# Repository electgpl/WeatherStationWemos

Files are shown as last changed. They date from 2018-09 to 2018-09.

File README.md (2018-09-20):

# Estación Meteorológica WiFi v1.0 

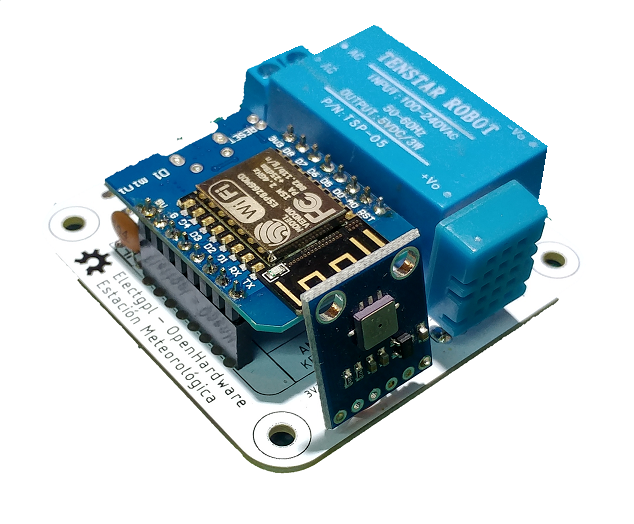
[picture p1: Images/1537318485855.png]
N|Solid


Esta es una estación Meteorológica Inalámbrica mediante WiFi, basada en el SoC ESP8266 para la comunicación y los sensores: BMP085/180, DHT11 y LDR.
Para una mejor precisión de medición, la temperatura se extrae del sensor Bosch en lugar del sensor DHT11, quedando así el DHT11 solo para indicar la humedad relativa.
El firmware cuenta con la biblioteca WiFiManager para aumentar la facilidad de autenticación para el usuario y los datos son enviados directamente a ThingSpeak.
Estos datos son enviados cada 5 minutos para mantener las buenas costumbres de frecuencia de datos en el servidor ThingSpeak, en el caso de parámetros meteorológicos no es necesaria la actualización constante de los datos, estos cambian de forma lenta.

## Controles - v1.0

  - Core - **ESP8266 - WEMOS D1 Mini**
  - Sensor de Presión y Temperatura - **BMP085 - BMP180**
  - Sensor de Humedad y Temperatura - **DHT11**
  - Sensor de Luminosidad - **LDR**
  - Botón de configuración para restablecer datos de fabrica
  - Servidor - **ThingSpeak**
  - Control WiFi - **WiFiManager**

## Alimentación

> Diseñado para ser alimentado con fuente de alimentación de 100 a 240Vac 3W

### Diseño

> Diseñado con EAGLE, en solo dos capas con componentes THT para facilitar
> la integración al alumno, el desarrollo del PCB en el hogar y mantener
> el menor costo posible.

### Medición OnLine en Tiempo Real ThingSpeak Channel 128756
https://thingspeak.com/channels/128756

Patrocinado
----
¿Dónde fabricamos nuestros PCBs?
Nuestros PCBs los fabricamos con la empresa PCBWay, esta empresa nos permite realizar pequeñas cantidades como prototipos rápidos para nuestros desarrollos a medida.
También nos permite realizar grandes producciones para realizar proyectos comerciales.
Servicio de prototipo de PCB por tan solo $5 las 10 unidades.
Cada nuevo miembro recibirá un bono de $5, más servicio express de 24Hs o 48Hs.
Servicio de ensamblado de PCB por $88 más envió gratis en todo el mundo, más esténcil, más componentes.
Un servicio de calidad!
https://www.pcbway.es/

N|Solid (https://www.pcbway.es/)

License
----

MIT

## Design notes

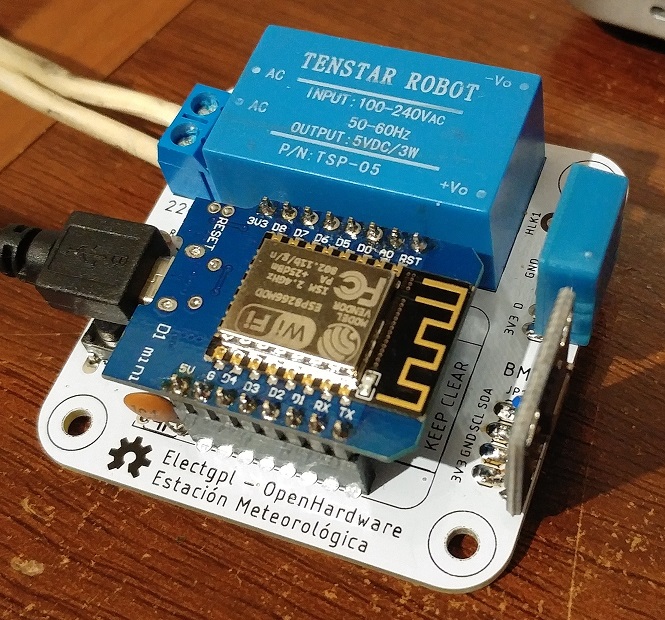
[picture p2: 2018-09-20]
Images/20180918_194005_HDR.jpg

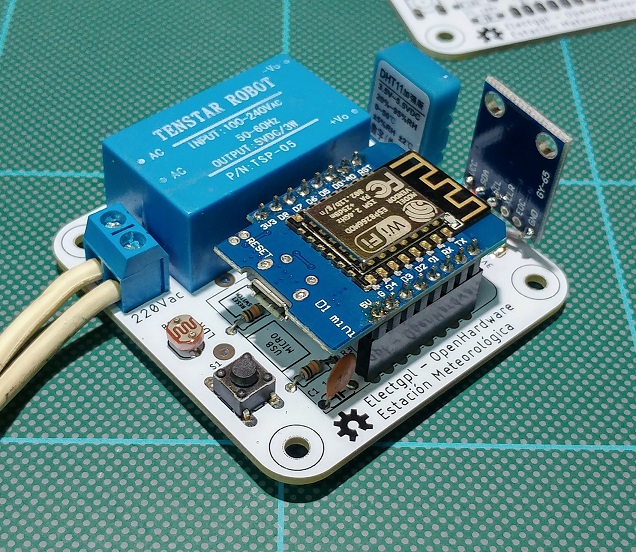
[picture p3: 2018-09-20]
Images/20180918_203112_HDR.jpg

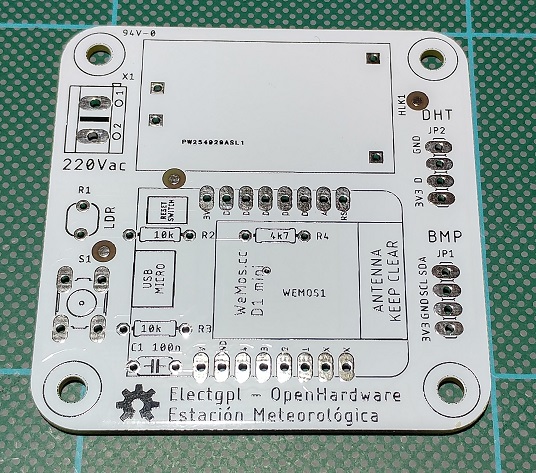
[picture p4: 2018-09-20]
Images/20180918_203201_HDR.jpg

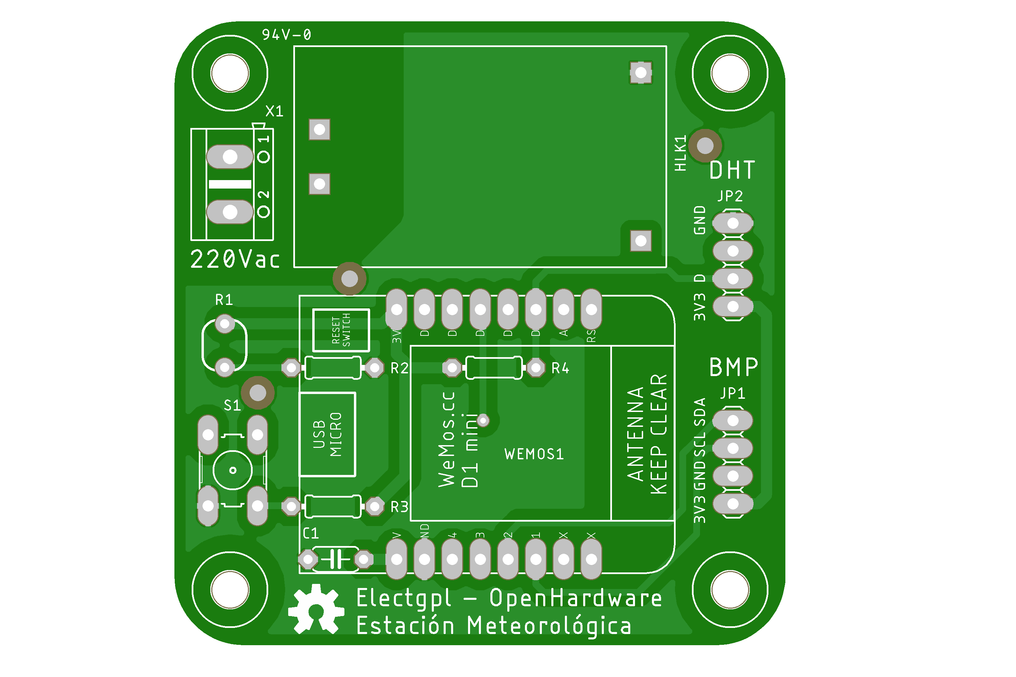
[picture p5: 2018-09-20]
Preview/EstacionESP8266_v1_T.png

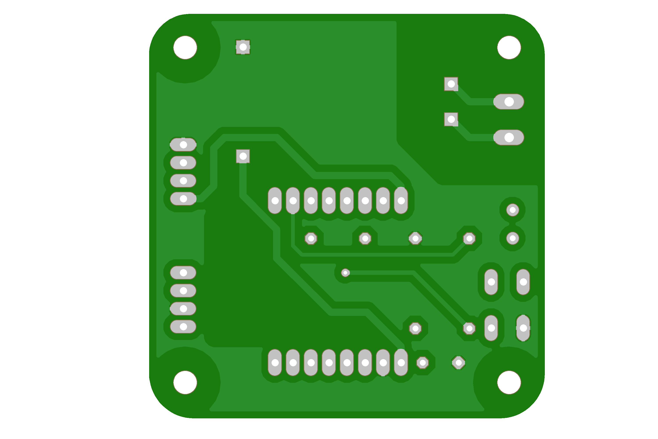
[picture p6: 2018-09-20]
Preview/EstacionESP8266_v1_B.png

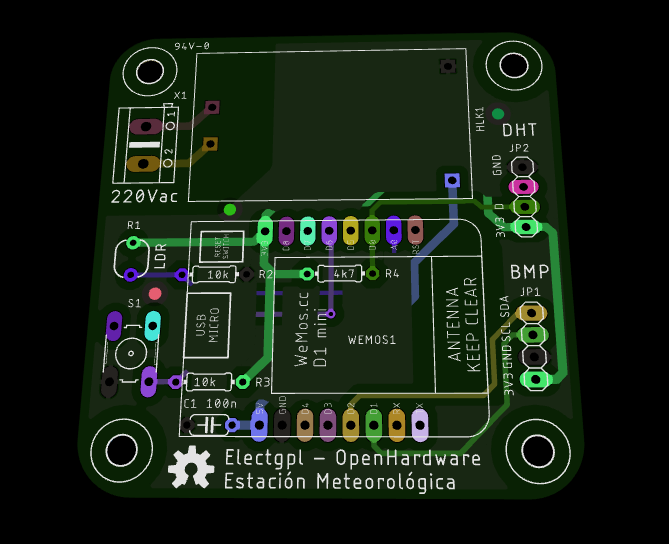
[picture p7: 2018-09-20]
Preview/2018-09-01 14_01_46-Window.png

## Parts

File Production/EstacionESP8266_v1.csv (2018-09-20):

Qty | Value | Device | Package | Parts | Description | MF | MPN | OC_FARNELL | OC_NEWARK | SPICEPREFIX
1 |  | 10-XX | B3F-10XX | S1 | OMRON SWITCH |  | B3F-1000 | 176432 | 36M3542
1 |  | AK500/2 | AK500/2 | X1 | CONNECTOR |  |  | unknown | unknown
2 |  | PINHD-1X4 | 1X04 | JP1, JP2 | PIN HEADER
1 |  | WEMOS-D1-MINI | WEMOS-D1-MINI | WEMOS1 | WeMos.cc
1 | 100n | C-EU050-024X044 | C050-024X044 | C1 | CAPACITOR, European symbol |  |  |  |  | C
2 | 10k | R-US_0204/7 | 0204/7 | R2, R3 | RESISTOR, American symbol |  |  |  |  | R
1 | 4k7 | R-US_0204/7 | 0204/7 | R4 | RESISTOR, American symbol |  |  |  |  | R
3 | FIDUCIAL1.5X3 | FIDUCIAL1.5X3 | FIDUCIAL-1.5X3 | JP3, JP4, JP5 | Fiducial Alignment Points
1 | HLK-PM013W | HLK-PM013W | HLK-PM01 | HLK1 | Hi-Link Power Supply
1 | LDR | PHOTOCELLPTH | PHOTOCELL | R1 | Photocell Also known as a CdS photoresistor. This is a low cost way to detect light levels. Resistance decreases with more incoming light. SparkFun SKU: SEN-09088
1 | OSHW-LOGOM | OSHW-LOGOM | OSHW-LOGO-M | U$5 | Open Source Hardware Logo This logo indicates the piece of hardware it is found on incorporates a OSHW license and/or adheres to the definition of open source hardware found here: http://freedomdefined.org/OSHW

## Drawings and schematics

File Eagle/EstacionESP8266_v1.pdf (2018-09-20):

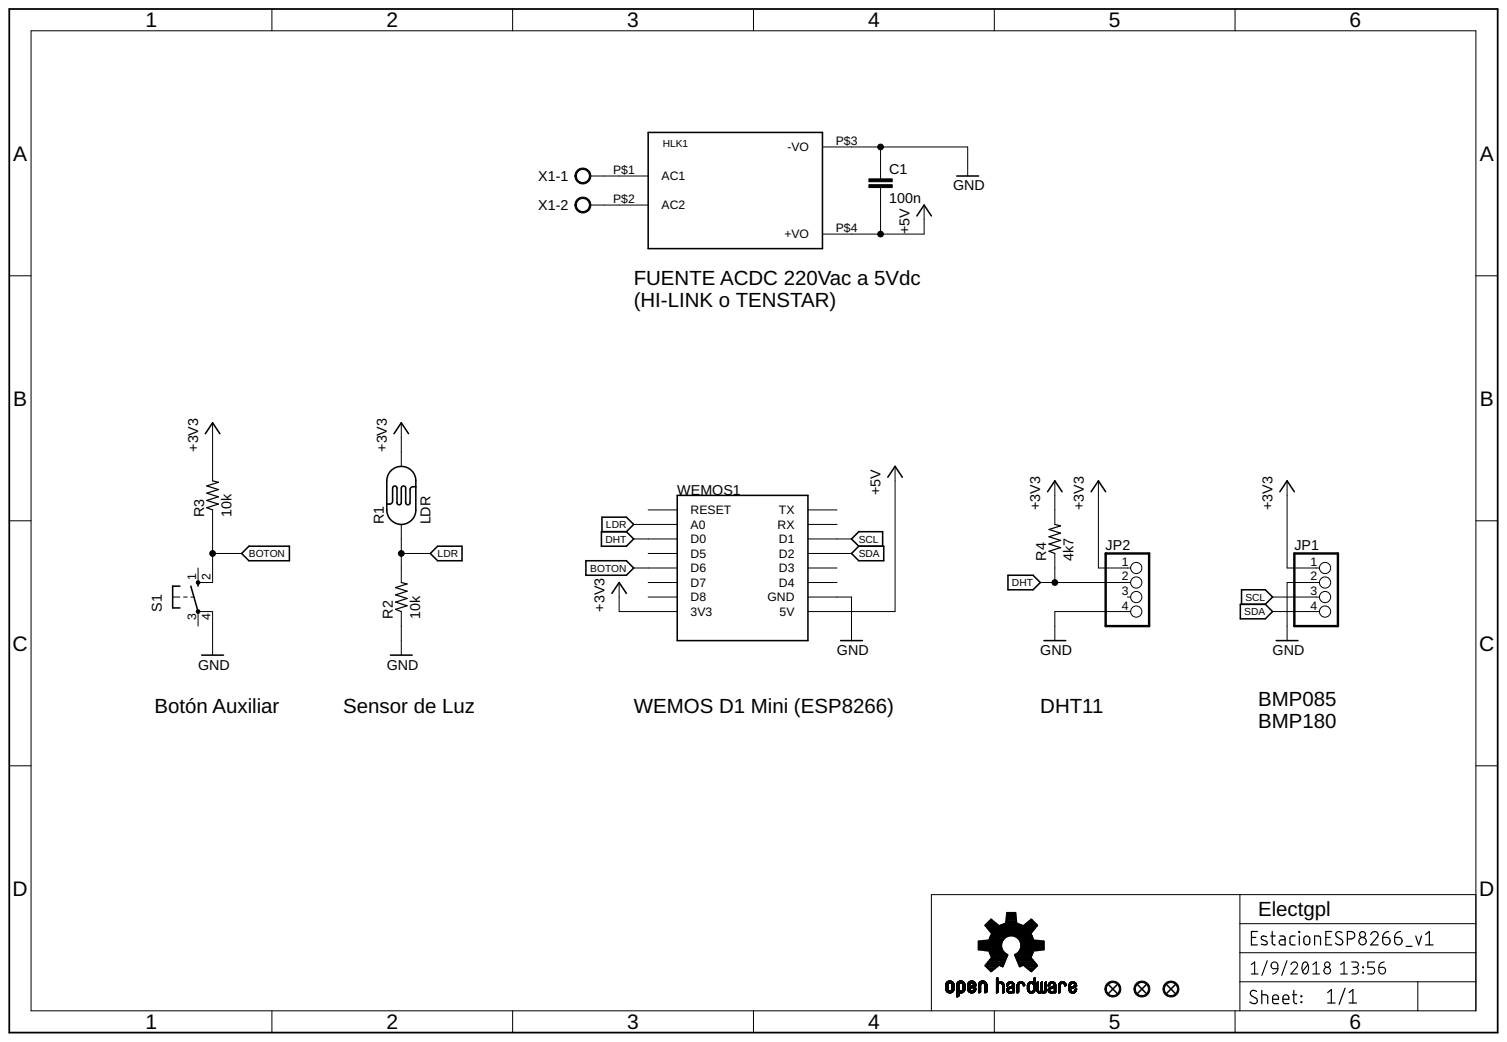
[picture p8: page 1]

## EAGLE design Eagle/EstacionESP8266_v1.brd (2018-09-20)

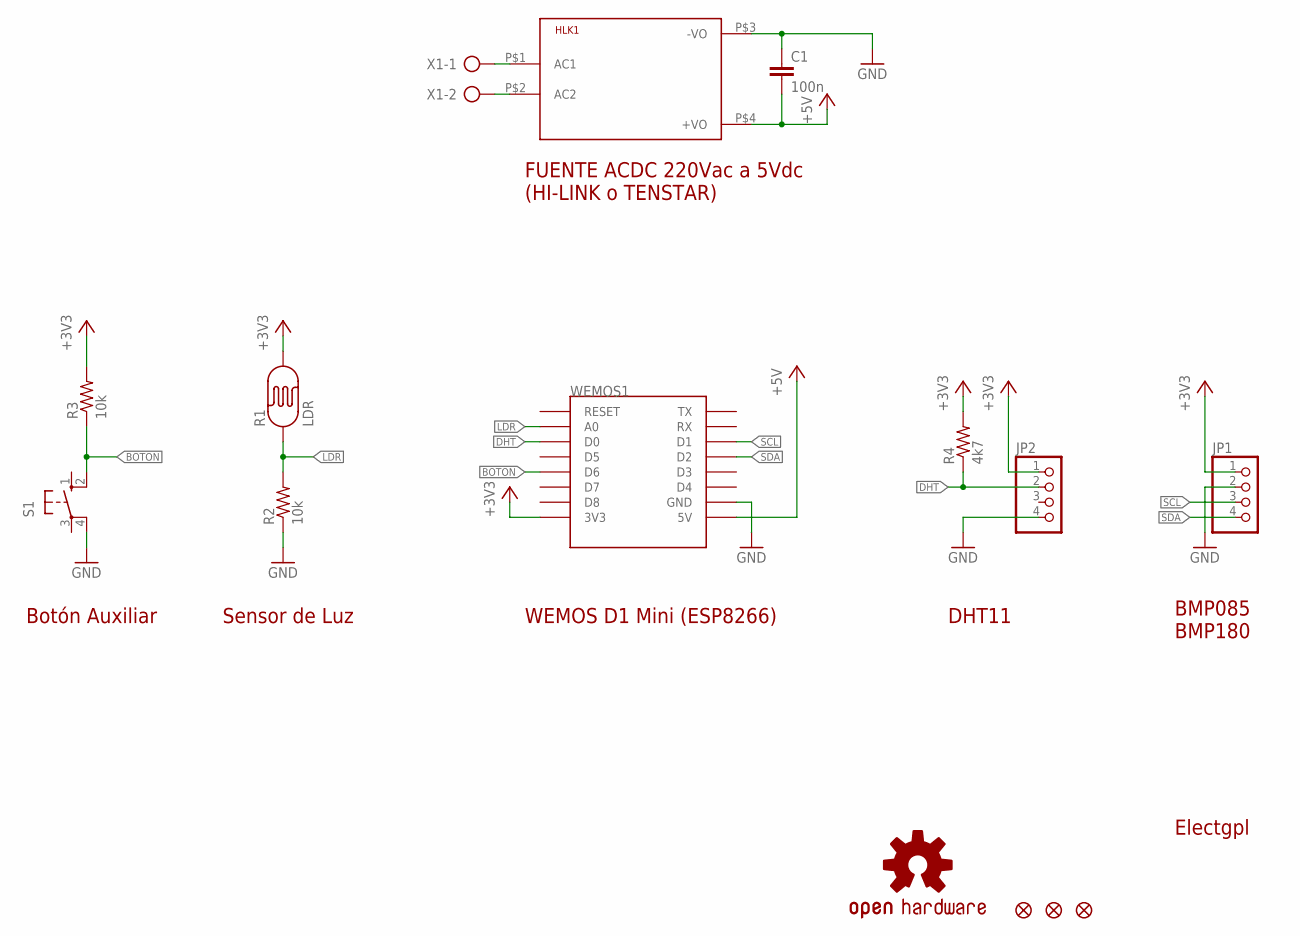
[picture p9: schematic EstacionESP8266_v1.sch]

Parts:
C1: 100n; C050-024X044
HLK1: HLK-PM013W; HLK-PM01
JP1, JP2: PINHD-1X4; 1X04
JP3, JP4, JP5: FIDUCIAL1.5X3; FIDUCIAL-1.5X3
R1: LDR; PHOTOCELL
R2, R3: 10k; 0204/7
R4: 4k7; 0204/7
S1: 10-XX; B3F-10XX
U$5: OSHW-LOGOM; OSHW-LOGO-M
WEMOS1: WEMOS-D1-MINI
X1: AK500/2

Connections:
+3V3: JP1.1, JP2.1, R1.2, R3.2, R4.2, WEMOS1.3V3
+5V: C1.2, HLK1.P$4 (+VO), WEMOS1.5V
BOTON: R3.1, S1.2 (S1), WEMOS1.D6
DHT: JP2.2, R4.1, WEMOS1.D0
GND: C1.1, HLK1.P$3 (-VO), JP1.2, JP2.4, R2.1, S1.4 (P1), WEMOS1.GND
LDR: R1.1, R2.2, WEMOS1.A0
unnamed: HLK1.P$1 (AC1), X1.1
unnamed: HLK1.P$2 (AC2), X1.2
SCL: JP1.3, WEMOS1.D1
SDA: JP1.4, WEMOS1.D2

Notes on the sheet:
Electgpl
BMP085 BMP180
DHT11
WEMOS D1 Mini (ESP8266)
Sensor de Luz
Botón Auxiliar
FUENTE ACDC 220Vac a 5Vdc (HI-LINK o TENSTAR)

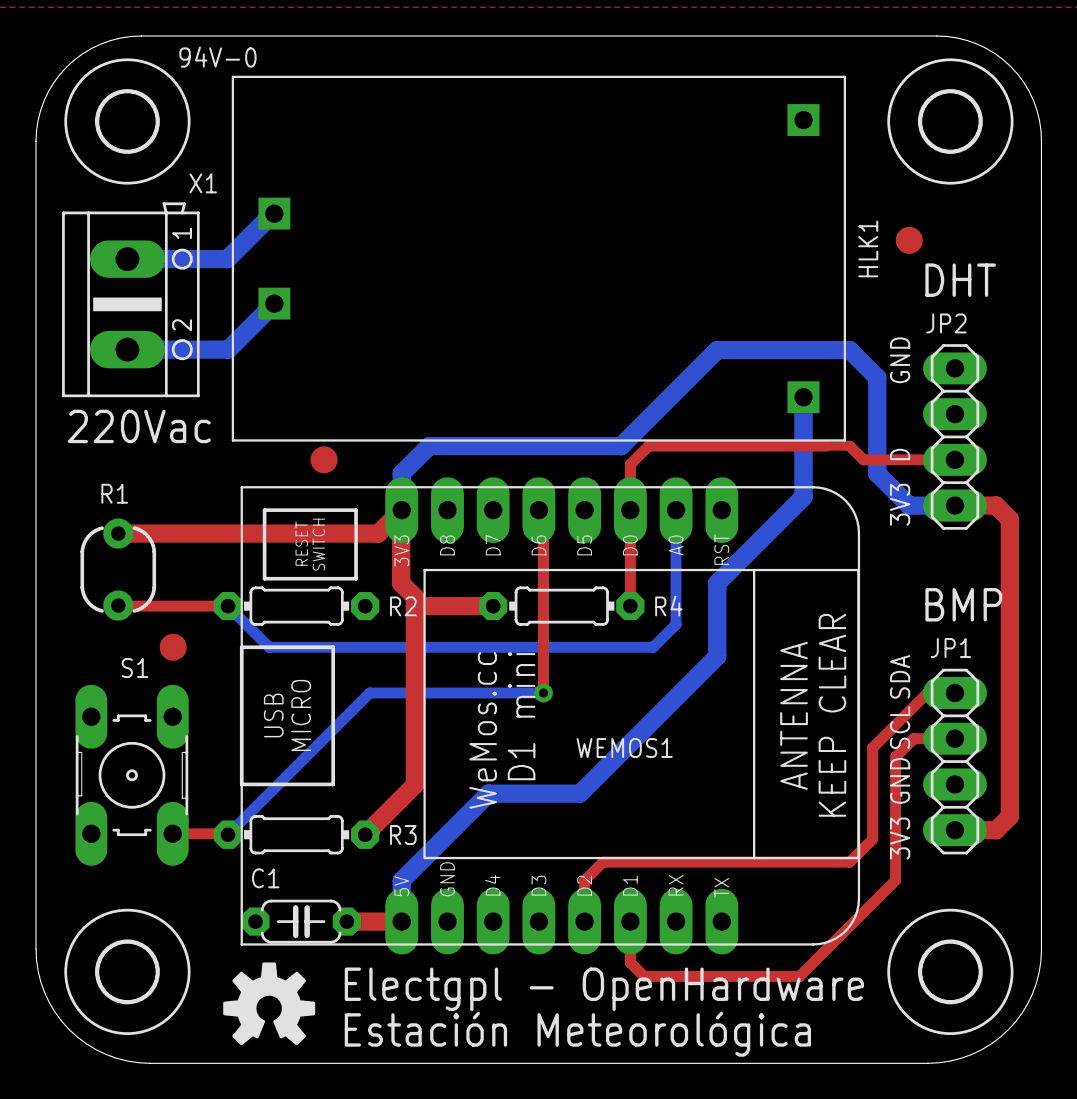
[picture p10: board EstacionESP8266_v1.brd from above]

Board: 2 copper layers, 55.9 x 57.1 mm, 19 parts (0 on the bottom side), 10 nets.

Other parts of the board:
U$1, U$2, U$3, U$4: 3,2

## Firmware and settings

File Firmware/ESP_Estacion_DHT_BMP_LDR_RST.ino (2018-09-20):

#include <ESP8266WiFi.h>          //https://github.com/esp8266/Arduino
#include <DNSServer.h>
#include <ESP8266WebServer.h>
#include <WiFiManager.h>         //https://github.com/tzapu/WiFiManager
#include <SimpleDHT.h>
#include <Wire.h>
#include <Adafruit_BMP085.h>

String apiKey = "APIKEY DE SU CUENTA THINGSPEAK";
const char* server = "api.thingspeak.com";
int pinDHT11 = D0;
int pinFACTORY = D6;
int timeOut = 0;
SimpleDHT11 dht11;
WiFiClient client;
Adafruit_BMP085 bmp;

void handleButton(){
   int debounce = 1000;
   if(digitalRead(pinFACTORY)==LOW){
      delay(debounce);
      if(digitalRead(pinFACTORY)==LOW){
         WiFiManager wifiManager;      
         wifiManager.resetSettings();
         delay(1000);
         ESP.reset();
      }
   }
}

void setup(){
   WiFiManager wifiManager;
   Serial.begin(115200);
   pinMode(pinFACTORY, INPUT);
   delay(10);
   // wifiManager.resetSettings();
   wifiManager.autoConnect("WS-Electgpl");
   Serial.println("Estacion Conectada a Internet");
   if(!bmp.begin()){
      Serial.println("Error en BMP085");
   }
}

void loop(){
   byte temperatura = 0;
   byte humedad = 0;
   float luminosidad = analogRead(A0);
   handleButton();
   if(dht11.read(pinDHT11, &temperatura, &humedad, NULL)){
      Serial.print("Error en DHT11");
      return;
   }
   if(timeOut==300){
      if(client.connect(server,80)){
         String postStr = apiKey;
         postStr +="&field1=";
         postStr += String(luminosidad);
         postStr +="&field2=";
         postStr += String((float)bmp.readTemperature());
         postStr +="&field3=";
         postStr += String((int)humedad);
         postStr +="&field4=";
         postStr += String((float)bmp.readPressure()/100);
         postStr += "\r\n\r\n";
         client.print("POST /update HTTP/1.1\n");
         client.print("Host: api.thingspeak.com\n");
         client.print("Connection: close\n");
         client.print("X-THINGSPEAKAPIKEY: "+apiKey+"\n");
         client.print("Content-Type: application/x-www-form-urlencoded\n");
         client.print("Content-Length: ");
         client.print(postStr.length());
         client.print("\n\n");
         client.print(postStr);
         Serial.println("% send to Thingspeak");
      }
      client.stop();
      Serial.print("luminosidad: ");
      Serial.print(luminosidad);
      Serial.print(" | temperatura BMP: ");
      Serial.print((float)bmp.readTemperature());
      Serial.print(" | temperatura DHT: ");
      Serial.print(temperatura);
      Serial.print(" | humedad: ");
      Serial.print(humedad);
      Serial.print(" | presion: ");
      Serial.println((float)bmp.readPressure()/100);
      timeOut=0; 
   }
   delay(1000);
   timeOut++;
   Serial.print("timeOut");
   Serial.println(timeOut);
}

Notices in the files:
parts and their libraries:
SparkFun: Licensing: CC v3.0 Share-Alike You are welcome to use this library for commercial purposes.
